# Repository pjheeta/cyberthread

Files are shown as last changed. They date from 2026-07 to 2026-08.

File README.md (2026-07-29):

# cyberthread

**WiFi-controlled fibre-optic hair for Burning Man.** Eight side-glow fibres woven
into braided hair, each lit by its own addressable LED. The electronics live in a
small box on the chest; only passive glowing fibre goes in the hair. Colour, patterns,
and a mic-reactive "glitch" mode are driven from an ESP32 and controlled from a phone.

The name is the concept: the *thread* is both the fibre woven through the hair and the
data thread driving it.

> **Status: pre-build / design complete.** The hard part (the fibre-to-LED coupler) is
> solved and printable. Remaining work is gated on one set of physical measurements
> taken with the strip in hand — see [Open items](#open-items).

---

## How it works

```
  phone ──WiFi──▶ ESP32 ──DAT/CLK──▶ SK9822 pixels ──▶ COUPLER ──▶ fibre ──▶ hair
                    ▲                 (8, in the box)   (the      (side-    (8 passive
                 I2S mic                                 custom     glow)     strands)
               (glitch mode)                             part)
```

A fibre makes no light of its own — it's a light pipe. Shine an LED into one end and
the whole strand glows that colour. So the design keeps every electronic part in a box
and sends only light up into the hair:

1. **ESP32-WROOM-32** runs the show — WiFi access point, phone web UI, render loop.
2. **8× SK9822 pixels** (APA102-family, clock + data) sit *in the box* as the light
   engine. One pixel per fibre = per-strand colour control.
3. The **coupler** presses each fibre end against its pixel. This is the only custom-
   fabricated part and the thing the whole build hinges on.
4. **Side-glow fibre** carries the light up and glows along its length.
5. An **INMP441 I²S mic** feeds amplitude to the ESP32 for the sound-reactive mode.

Firmware is either **WLED** (free, has an AudioReactive usermod that supports the
INMP441 natively — no code) or hand-rolled FastLED (SK9822 is already familiar from a
prior POV-wheel project).

### Why fibre and not LED strip in the hair

A strip *can* go in the hair and gives real per-pixel "rain" down each strand — but a
flat flex-PCB doesn't drape; it reads as hardware braided into hair. Fibre drapes like
hair and looks like the hair itself is glowing. The trade is that fibre has no spatial
resolution along its length (a single fibre is one colour end-to-end), so per-strand
addressability is the ceiling, not per-*pixel* rain down a strand. That trade was made
deliberately: the look won.

---

## The coupler

A small block with a **groove** on the underside and a **row of holes** through the top.

- The SK9822 strip drops into the groove. The groove is sized to the strip width so it
  can only sit one way — which **auto-aligns every LED under its hole.** No aligning by
  eye.
- Each hole holds one fibre pointed straight down at one LED. The fibre bottoms out
  **dry against the LED face** — nothing in the optical gap.
- A dab of glue on the fibre shaft *above* the block retains it. **Never glue in the
  hole or on the LED** — it fogs the light path and can't be undone.

It's parametric ([`hardware/coupler/cyberthread_coupler.scad`](hardware/coupler)): the
same file makes the block for any strip density by changing `pitch` and `strip_w`.

| Strip | Pitch (c-c) | Strip width | Block length | Print |
|---|---|---|---|---|
| 30 LED/m  | ~28–33 mm* | 10 mm | ~212 mm | full, or 2× halves |
| 100 LED/m | ~10 mm | 10 mm | ~78 mm | single piece |
| 144 LED/m | ~6.94 mm | 12 mm | ~65 mm | single piece |

\* *Pitch to be confirmed by measurement — see Open items. The LED itself is a fixed
5×5 mm (5050) package at every density; only spacing changes.*

**Print notes:** black **PETG** (not PLA — softens in a warm box; not CF — rough holes,
needs a hardened nozzle). Orient channel-opening **up** → holes print clean, no
supports, no bridging. FDM shrinks holes slightly, so **test-fit a fibre and tune
`hole_comp`** before printing the final part.

---

## Bill of materials

| Part | Spec | Notes |
|---|---|---|
| Controller | ESP32-WROOM-32 | owned |
| Light engine | 8× SK9822 pixels | cut from strip stock; owned |
| Fibre | 2 mm side-glow PMMA, ~10 m | **not** end-glow. Long-lead item — order first |
| Coupler | black PETG print | the one fabricated part; STLs in repo |
| Mic | INMP441 (I²S) | optional; enables glitch mode. 3.3 V, not 5 V |
| Box | plastic project box | **never metal** — kills the WiFi AP |
| Power | USB power bank | ~1 A draw → runs all night |
| Chain | 550 paracord + black heatshrink | paracord carries load; fibre carries none |
| Safety | magnetic breakaway | necklace in a crowd must pop apart when snagged |
| Coat | acrylic conformal coating | playa dust is alkaline/conductive |

Realistic out-of-pocket, owning the ESP32/SK9822/consumables: **~$50–75.**

---

## Repo layout

```
cyberthread/
├── README.md
├── hardware/
│   └── coupler/
│       ├── cyberthread_coupler.scad     ← parametric source (edit this)
│       ├── coupler_30ledm_FULL.stl
│       ├── coupler_30ledm_LEFT_half.stl
│       ├── coupler_30ledm_RIGHT_half.stl
│       ├── coupler_144ledm_FULL.stl
│       └── PRINT.md                      ← print + fit-test instructions
├── firmware/                             ← WLED config / FastLED sketch (TBD)
└── docs/
    └── build-guide.html                  ← illustrated build guide
```

---

## Build sequence

1. **Dark-room test first.** One pixel, one polished fibre, lights off. Confirms the
   whole idea reads before anything is fabricated.
2. Cut an 8-pixel SK9822 run; solder `5V/GND/DAT/CLK` to the **input** end (arrows point
   away from it). Avoid the 0.5 m factory solder-joints — pitch is irregular there.
3. Flash the ESP32 (WLED or FastLED); get pixels + phone control working on the bench.
4. Print the coupler; **test-fit a fibre**, tune `hole_comp`, reprint if needed.
5. Prep fibres (razor-cut, sand, flame-polish), seat dry, retain from behind, wrap the
   junction reflective.
6. Bench-test all 8 strands. Dull strand = re-seat that fibre. Then soak-test on
   battery for runtime + heat.
7. Chain: paracord core + heatshrink jacket + magnetic breakaway.
8. Braid in, dress-rehearse in the dark on battery before the playa.

---

## Open items

Everything below is gated on measuring the **actual strip** (blocked until home ~Aug 10):

- [ ] **Centre-to-centre pitch** — ruler on centre of LED #1, read centre of LED #11,
      ÷10. Ends the 28-vs-33 mm ambiguity for the 30/m strip.
- [ ] **Which density** is actually being used (30 / 100 / 144) → picks the block.
- [ ] **Fibre outer diameter** → sizes the holes (`fiber_d`, currently assumed 2 mm).
- [ ] Confirm side-glow fibre is **ordered / en route** (the long pole).
- [ ] Firmware decision: WLED vs. hand-rolled FastLED.

Once measured, regenerating the correct STL is a two-line edit to the `.scad`.

---

## Lessons / decisions log

- Fibre must be **side-glow**, not end-glow, or it only lights at the tip.
- Coupling is the whole game: a scissor-crushed or unpolished fibre end scatters light;
  an air gap or glued gap kills brightness. Razor-cut, sand, flame-polish, seat dry.
- **The LED is a constant 5050 (5×5 mm) at every density** — only pitch/width change,
  which is why one parametric file covers all strips.
- Nominal pitch (`1000 ÷ density`) is *not* reliable — factory spacing and 0.5 m splices
  drift it. Measure, don't assume; a per-hole error accumulates to a total miss by hole 8.
- Power bank on the belt beats a LiPo on the neck (heat/puncture); a night-only piece
  never bakes, so hot glue and simple sealing are fine.

---

*Personal build. Shared in case it's useful to anyone chasing the same look.*

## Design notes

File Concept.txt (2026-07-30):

Path A — WLED: you flash, you don't write. WLED is C++/Arduino firmware, so "no issues with Arduino" makes it fully available to you — but you barely touch code. You flash the binary, open its web UI, tell it "SK9822, 8 pixels, these pins," enable the AudioReactive usermod for your INMP441, and you're done. The entire architecture I walked through — two-core split, mode table, web layer, mic subsystem, NVS persistence — you inherit, pre-built and battle-tested. Your work becomes configuration, not programming.

how would I control it on the palya

Good — WLED it is, and "how do I control it on the playa" is exactly the right question to poke at, because the playa breaks the assumptions WLED's control model is normally built on. Let me walk through how control actually works, then the three things about the playa specifically that you have to design around.

How WLED control works, normally

WLED serves its own web interface. You connect a phone to it and control it from a browser or the WLED app — brightness, color, effect, speed, on/off, presets. There's no cloud, no account, nothing phones home. That "no internet needed" part is what makes it viable out there at all.

But there's a catch in the default setup: out of the box, WLED wants to join your home WiFi, and you control it as another device on that network. There is no home WiFi on the playa. So the default model doesn't apply, and this is the thing to get right before you go.

The mode that actually works out there: AP mode

WLED has a built-in access point — the ESP32 broadcasts its own WiFi network. Your phone connects directly to the wearable itself; no router, no infrastructure. This is the playa answer.

How it behaves: when WLED boots and can't find a known network (which is always, out there), it falls back to broadcasting an AP — typically named WLED-AP. You connect your phone to that network, and WLED's control page opens automatically (a captive portal, like a hotel WiFi splash). From there you have the full interface.

To make this reliable, before you leave you'd set WLED to AP mode always-on (not just as a fallback) in its WiFi settings, so it isn't wasting time scanning for home networks that aren't there. You give the AP a name and a password so it's yours and not open to every passerby.

So the on-playa flow is: wearable powers on → broadcasts its AP → you open your phone's WiFi, tap your network, the control page appears → change color/effect/brightness/mode. That's it. Works in the deep playa with zero infrastructure.

Now the three playa-specific problems, because the above is the easy version:

1. Your phone fights you over the "no internet" network. This is the one that'll actually bite you. When your phone connects to an AP with no internet — which WLED's AP is — modern phones detect "no internet here" and often auto-disconnect, or pop "this network has no internet, stay connected?" every time, or silently drop back to cellular. On the playa, where you'll connect and reconnect a lot, this is genuinely annoying. Mitigations: tell your phone to stay connected to this network / disable "auto-switch to mobile data" for it, and on Android turn off "switch to mobile network if no internet." Set this up and test it at home before you go, because fighting your phone's captive-portal logic at 2 a.m. in the dust is miserable.

2. RF soup. The playa is thousands of people, hotspots, LED-suit controllers, everyone's phone. 2.4 GHz gets crowded. AP mode helps because you're the only client on your own network, but connection can still be flaky in a dense crowd. Practical answer: you don't need a persistent connection. You connect, change the look, disconnect. WLED keeps running the selected mode with no phone attached. So treat control as "occasional adjustment," not "live tether."

3. You often can't reach your phone, or don't want to. Half the time you're dancing, riding, hands full, phone buried. So lean on WLED features that mean you don't need the phone most of the night:

Presets + playlists. Save your favorite looks as presets, then build a playlist that auto-cycles through them on a timer. Set it once; it runs all night untouched. This is the big one for a wearable — you may barely touch the phone after setup.
Macros / on-boot preset. WLED can boot straight into a chosen preset, so it comes up right every time you swap the battery.
The mic mode is autonomous. AudioReactive glitch mode needs no phone at all — it just reacts to the music around you. Set it and forget it.
The honest recommendation for playa control: set up AP mode always-on, build 3–5 presets (your purple, your glitch, a slow breathing fade, etc.) and a playlist that cycles them, and set a boot preset. Then the phone becomes optional — you pull it out only when you want to deliberately override the look, connect, tap, disconnect. That's far more robust than expecting a live connection to hold in that environment.

One thing worth knowing exists, though I'd not rely on it: WLED supports physical controls too — a button on a GPIO can cycle presets or toggle power. For a wearable where the phone is a hassle to reach, a single concealed button at your chest box that advances through your presets is a really nice touch. No phone at all: press to change look. If you want that, it's one more GPIO and a config line, and it might be the most playa-appropriate control of all — because it works with dusty hands, no screen, no reconnecting.

Want me to lay out the specific WLED settings to configure before you leave — the AP setup, the preset/playlist structure, the boot preset, and optionally that hardware button — as a pre-departure checklist you can run through at home while you still have a calm network to test on?

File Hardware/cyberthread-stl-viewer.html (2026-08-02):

CYBERTHREAD·STL viewerPRO

Open STL Wireframe Grid Bounds Spin Light Reset view

### Model

file—

triangles—

size X—

size Y—

size Z—

longest—

drag orbit scroll zoom

right-drag / shift-drag pan

## Drop an STL file here

Or click Open STL. Handles both ASCII and binary STL, including the 80-byte-header binaries that trip up naive parsers. Units are read as millimetres.

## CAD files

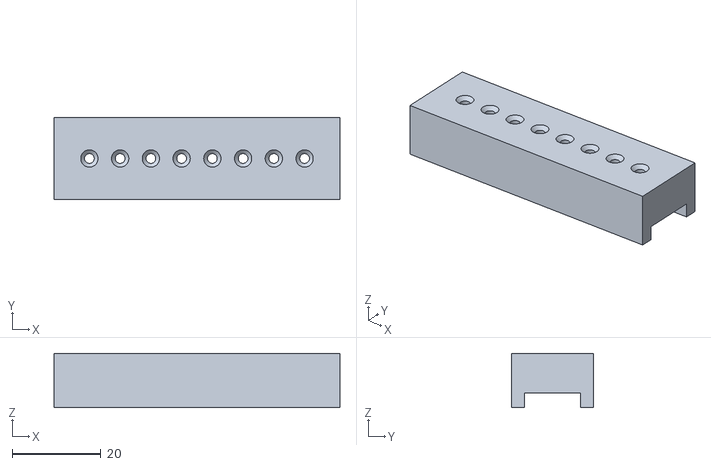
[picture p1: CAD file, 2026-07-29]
Hardware/coupler_144ledm_FULL.stl
64.6 x 18.6 x 12.3

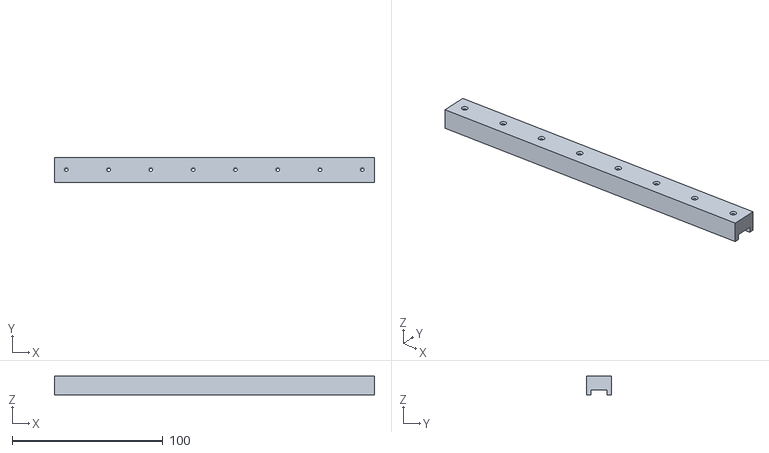
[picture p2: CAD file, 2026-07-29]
Hardware/coupler_30ledm_FULL.stl
212.0 x 16.6 x 12.3

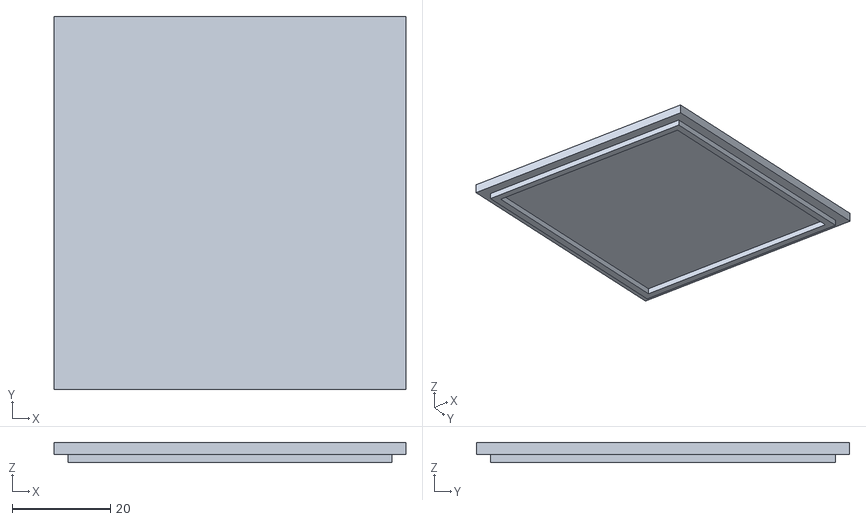
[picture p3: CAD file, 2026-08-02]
Hardware/enclosure_144_LID.stl
71.6 x 75.9 x 4.10

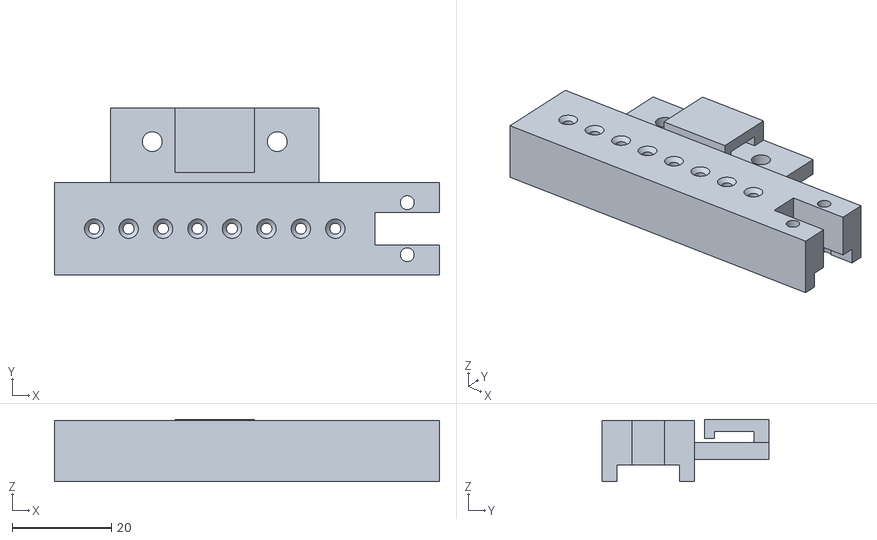
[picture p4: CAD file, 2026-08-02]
Hardware/coupler_144_NECKMOUNT.stl
77.6 x 33.6 x 12.5

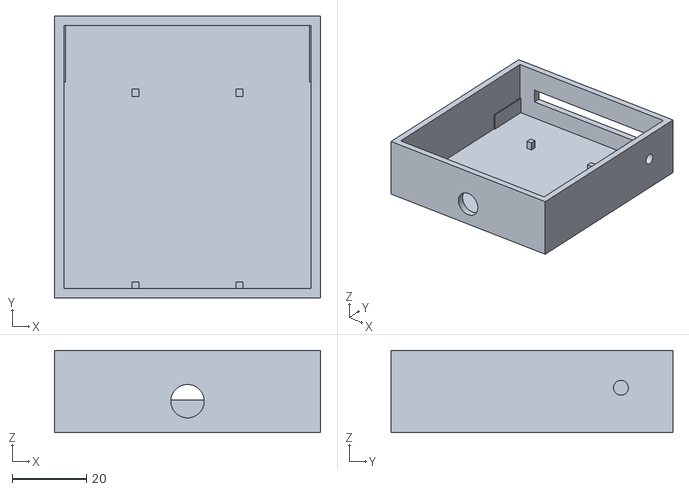
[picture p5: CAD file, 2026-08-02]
Hardware/enclosure_144_TRAY.stl
71.6 x 75.9 x 22.2

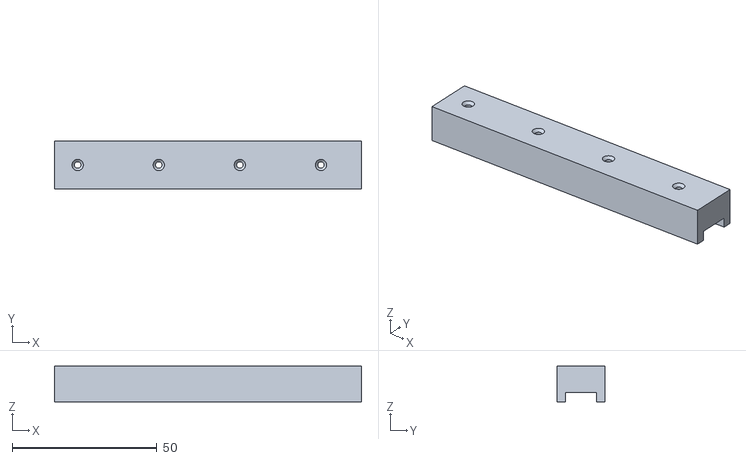
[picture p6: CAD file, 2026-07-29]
Hardware/coupler_30ledm_LEFT_half.stl
106.0 x 16.6 x 12.3

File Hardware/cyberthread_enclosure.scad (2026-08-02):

// ============================================================
//  CYBERTHREAD — printed enclosure (v0, parametric)
//  The coupler drops in at the TOP; fibres exit the top wall
//  and run up to the hair. The ESP32 sits in the body. USB
//  power enters the bottom (battery lives on your belt).
//  Prints as a tray (open top) + a friction-fit lid.
// ============================================================

/* ---- coupler outer size (match your coupler .scad output) ---- */
cpl_l = 65;     // length / hole-row.  144/m = 65,  30/m = 212
cpl_w = 18.6;   // width.              144/m = 18.6, 30/m = 16.6
cpl_h = 12.3;   // height

/* ---- ESP32 board bay   ### CONFIRM your board's real size ### ---- */
esp_l = 52;     // board length (38-pin devkit ~ 52; 30-pin ~ 48)
esp_w = 28;     // board width  (~ 25.4–28)
esp_h = 13;     // height incl. header pins

/* ---- build params ---- */
wall    = 2.5;
floor_t = 2.0;
clr     = 0.8;   // clearance around parts
gap     = 5;     // gap between coupler and ESP bay
usb_d   = 9;     // USB cable pass-through (fits a grommet)
mic_d   = 4;     // mic port
lip     = 1.6;   // lid lip depth
lip_clr = 0.35;  // lid fit clearance
$fn = 48;

/* ---- derived ---- */
in_x  = max(cpl_l, esp_w) + 2*clr;
in_y  = cpl_h + gap + esp_l + 2*clr;
in_z  = max(cpl_w, esp_h) + 2*clr;
out_x = in_x + 2*wall;
out_y = in_y + 2*wall;
tray_h = floor_t + in_z;

// key interior anchors
cpl_y0 = wall + in_y - cpl_h;      // coupler pushed against +Y wall
cpl_x0 = wall + (in_x-cpl_l)/2;
slot_z = floor_t + cpl_w/2;        // fibre row height
esp_y0 = wall + clr;               // ESP at the bottom (low Y)
esp_x0 = wall + (in_x-esp_w)/2;

module tray() {
  difference() {
    cube([out_x, out_y, tray_h]);                 // shell
    translate([wall, wall, floor_t])
      cube([in_x, in_y, in_z + 2]);               // hollow, open top

    // fibre exit slot in +Y wall, aligned to the hole row
    slot_len = cpl_l - 12;
    translate([out_x/2 - slot_len/2, out_y - wall - 0.6, slot_z - 2.5])
      cube([slot_len, wall + 1.2, 5]);

    // USB power entry, -Y wall, at ESP height
    translate([out_x/2, -0.6, floor_t + esp_h/2])
      rotate([-90,0,0]) cylinder(d=usb_d, h=wall+1.2);

    // mic port, +X side wall, up near the coupler end
    translate([out_x-wall-0.6, out_y - 14, floor_t + in_z/2])
      rotate([0,90,0]) cylinder(d=mic_d, h=wall+1.2);
  }

  // coupler locating ribs (stop it sliding in X, hold against +Y wall)
  for (x=[cpl_x0-2.4, cpl_x0+cpl_l+0.4])
    translate([x, cpl_y0-3, floor_t]) cube([2, cpl_h+3, min(cpl_w,6)]);

  // ESP corner nubs (board drops between them; tape/glue to secure)
  for (dx=[0, esp_w], dy=[0, esp_l])
    translate([esp_x0+dx-1, esp_y0+dy-1, floor_t]) cube([2,2,3]);
}

module lid() {
  translate([0, out_y + 8, 0]) {
    cube([out_x, out_y, wall]);                    // plate
    // lip that drops into the interior
    translate([wall+lip_clr, wall+lip_clr, -lip])
      difference(){
        cube([in_x-2*lip_clr, in_y-2*lip_clr, lip]);
        translate([2,2,-1]) cube([in_x-2*lip_clr-4, in_y-2*lip_clr-4, lip+2]);
      }
  }
}

tray();
lid();

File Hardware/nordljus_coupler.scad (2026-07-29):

// ============================================================
//  NORDLJUS — SK9822 -> fibre coupler block   (parametric)
//  Holds 8 fibres, one over each LED. The strip drops into a
//  channel on the underside so the holes self-align to the LEDs.
//
//  MEASURED VALUES (from BTF spec sheet):
//    30 LED/m  : pitch 28.0 mm, strip width 10 mm
//    144 LED/m : pitch 6.94 mm, strip width 12 mm
// ============================================================

pitch      = 28.0;      // 30/m = 28.0  |  144/m = 6.944   ### confirm ###
strip_w    = 10.0;      // 30/m = 10    |  144/m = 12
fiber_d    = 2.0;       // fibre OUTER diameter (mm)        ### measure ###
num_holes  = 8;

hole_comp  = 0.20;      // FDM hole-shrink compensation (tune on a test print)
strip_clr  = 0.6;
pcb_t      = 1.0;
led_h      = 1.8;
roof       = 9.0;
wall       = 3.0;
end_margin = 8.0;
chamfer    = 0.9;

segment    = 0;         // 0 full | 1 LEFT half | 2 RIGHT half

$fn = 64;

hole_d    = fiber_d + hole_comp;
channel_w = strip_w + strip_clr;
channel_d = pcb_t + led_h + 0.5;
height    = channel_d + roof;
width     = channel_w + 2*wall;
length    = 2*end_margin + (num_holes-1)*pitch;
x_split   = end_margin + (num_holes/2 - 0.5)*pitch;
function hx(i) = end_margin + i*pitch;

module block_full() {
  difference() {
    cube([length, width, height]);
    translate([-1, (width-channel_w)/2, -0.1])
      cube([length+2, channel_w, channel_d+0.1]);
    for (i=[0:num_holes-1])
      translate([hx(i), width/2, channel_d-0.1])
        cylinder(d=hole_d, h=height-channel_d+0.2);
    for (i=[0:num_holes-1])
      translate([hx(i), width/2, height-chamfer])
        cylinder(d1=hole_d, d2=hole_d+2*chamfer, h=chamfer+0.05);
  }
}

if (segment==0) block_full();
else if (segment==1)
  intersection(){ block_full(); translate([-1,-1,-1]) cube([x_split+1, width+2, height+2]); }
else
  intersection(){ block_full(); translate([x_split,-1,-1]) cube([length-x_split+1, width+2, height+2]); }

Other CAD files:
Hardware/coupler_30ledm_RIGHT_half.stl

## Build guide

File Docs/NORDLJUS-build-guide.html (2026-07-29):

# Nordljus

Fibre-optic hair system · WiFi · 8 strand

Assembly Instructions ESP32-WROOM-32 · APA102 Design no. BRC-26

All electronics stay in the box. Only passive fibre goes in your hair. Read every panel before you cut anything — steps 1 and 2 decide how bright this ends up, and they are the two you cannot redo without starting over.

## Parts

ESP32-WROOM-32

×1

you own this

74AHCT125

×1

level shifter, DIP

APA102 pixels

×8

cut from bike-wheel stock

Side-glow fibre

10 m

3 mm PMMA · not end-glow

INMP441 mic

×1

I²S digital

Capacitors

3+

1000 µF · 470 µF · 0.1 µF

USB power bank

×2

10 000 mAh · on your belt

Project box

×1

plastic only — never metal

Magnetic breakaway

×1

safety disconnect

Coupling block

×1

8 holes · you make this

550 paracord

1 m

carries all the weight

Heatshrink

1 kit

black · 3:1 adhesive-lined

Conformal coat

×1

dust is corrosive

Grommets + fuse

1 kit

seal every box exit

Grey = already in your parts drawer

## Assembly

1

Do not rush this

Cut 8 fibres, each about 70 cm (box → top of head → down the braid, plus slack). Cut with a fresh razor blade against a hard surface — never scissors. Scissors crush the core and the end scatters light instead of accepting it. Then sand the LED end flat on fine paper and flame-polish it briefly until it goes glassy. This single surface is the biggest brightness lever in the whole build.

2

Make the one hard part once

Drill 8 holes in one block — Delrin, aluminium, or a print — at exactly your strip's pixel pitch (144/m ≈ 6.9 mm; measure yours). Size them so fibre press-fits snugly. The fibre end must physically touch the pixel's face: an air gap throws light away. Wrap the whole junction in reflective tape or white heatshrink to bounce stray photons back into the fibre. Doing all eight couplings as one part is the entire reason this build is tractable.

3

Cut an 8-pixel run from your APA102 strip and solder four wires to its input end: 5V, GND, DI, CI. The strip has arrows printed on it — data flows one way only. Solder to the end the arrows point away from, or nothing lights and you will blame the code.

4

The hour-eating mistake lives here

Power the shifter at 5V (single-supply — that's how it reads 3.3 V as HIGH and puts out clean 5 V). Add a 0.1 µF across its Vcc/GND. Tie pins 1 and 4 (/OE) to GND. They are active-low; leave them floating and the outputs stay dark while every wire looks perfect. This is the single most common way to lose an evening on this build.

5

Wire the mic for glitch mode. L/R to GND puts it on the left channel — your I²S read expects that. Mount it so the little port hole faces out of the box toward the music, not into a wiring bundle.

6

Brownout insurance

Feed pixel 5 V from the rail directly — never through the ESP32's regulator. Star all grounds to one point. Then the caps: 1000 µF across the rail near the pixels, 470 µF across the ESP32's 3V3/GND. That second one is not optional — ESP32 WiFi transmit spikes hard, and without it you get Brownout detector was triggered resets mid-show, on playa, in the dark.

7

Before glue. Before coat. Before anything.

Flash it, join the AP from your phone, cycle every mode, and check that all eight strands light and match. A dull strand means a bad coupling — pull that fibre, re-polish, re-seat. Do this while everything is still open and reversible. Every mistake in this build is cheap right now and expensive in four steps' time.

8

Brush conformal coat over the board and solder joints — mask the mic port, the connectors, and the pixel faces. Drop silica gel in the box. Grommet and hot-glue every cable exit. Playa dust is alkaline and mildly conductive; uncoated joints start failing around day four.

9

Cord takes the load. Fibre takes none.

Bundle the paracord and all 8 fibres, then sleeve the lot in black heatshrink — that's your chain. The paracord is anchored at both ends and carries every gram; the fibre floats loose inside carrying nothing. If the fibre ever takes the box's weight, it will creep, whiten, and dim over a week of movement. Add strain relief where the chain enters the box and where it meets the braid — both flex points.

10

Fit the magnetic breakaway in the chain between box and head. Braid the 8 fibres into tight tracks against the scalp so the surrounding hair conceals them and only the glow shows. The breakaway is a genuine safety part — anything worn around the neck in a crowd of bikes and hugs must come apart when it snags, not pull your head with it.

## Do not

A metal enclosureFaraday cage. Your AP dies inside it and you will debug firmware for a night. Plastic only, and keep the antenna end clear.

A LiPo pouch on your neckCrush, puncture, dust-short — and a cell that vents does it against your throat. Power bank on the belt, always.

Scissors on fibreA crushed end scatters light back out instead of accepting it. Razor, sand, flame-polish. Every time.

Floating /OE pinsPins 1 and 4 to GND. Otherwise: perfect wiring, correct code, zero light, four lost hours.

Fibre bearing the box's weightAnchor the paracord at both ends. Loaded fibre creeps and dims over a week of movement.

Sealing before you bench-testStep 7 exists so that a bad coupling costs you a minute, not a rebuild. Nothing gets glued until all eight strands light.

## Cost

Item | New | Yours
ESP32-WROOM-32in your drawer | $7 | $0
APA102 pixels8 cut from bike-wheel stock | $18 | $0
Capacitors, silicone wire, heatshrink, paracordexisting kits | $40 | $0
Side-glow fibre, 10 m3 mm PMMA — buy long, you'll ruin ends learning to polish | $20 | $20
USB power banks ×2the single biggest line; swap-and-solar for the week | $45 | $45
Conformal coatingnon-negotiable for dust | $14 | $14
Magnetic breakaway + magnetic USB-Csafety, twice | $22 | $22
Project box (plastic) | $10 | $10
INMP441 micships as a 3–5 pack | $8 | $8
74AHCT125 level shifter | $5 | $5
Coupling block stockDelrin offcut, or free if you print it | $8 | $8
Grommets, PTC fuse, silica | $18 | $18
Spare ESP32buy it. one brownout-bricked board on playa ends the project | $7 | $7
Total | $222 | $157

If a strand goes dark, it is the coupling — not the code. Pull the fibre, re-polish the end, re-seat it against the pixel. It is the coupling roughly every time.

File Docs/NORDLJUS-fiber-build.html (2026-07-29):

# Nordljus

Fibre-optic hair system · SK9822 light engine

Build & Coupler GuideESP32 · SK9822 · 8 fibreDesign no. BRC-26 · rev C

Eight LEDs live in a box on your chest. Eight fibres carry their light up into your braids. Nothing electronic goes in your hair — only glowing plastic. The whole build is parts you already own, plus fibre. The one thing you fabricate, and the one thing that decides whether this looks brilliant or dim, is the coupler — so this guide is built around it.

What changed from the strip idea: the SK9822 strip is no longer worn in your hair — it goes in the box as the light source. Fibre replaces it in the hair because fibre drapes and a strip does not. Same part you know from the bike wheel; new job.

## Parts

ESP32-WROOM-32

×1

you own this

SK9822 strip

8 px

from bike-wheel stock

Side-glow fibre

10 m

2 mm PMMA · not end-glow

INMP441 mic

×1

glitch mode · optional

Coupling block

×1

you make this

Project box

×1

plastic — never metal

Power bank

×1

~1A draw · runs all night

Mag breakaway

×1

safety disconnect

Paracord + heatshrink

kit

chain core & jacket

Reflective tape

scrap

wraps the coupler

Grey = already in your drawer

## How it fits together

## The coupler — in detail

A fibre makes no light of its own. It is a pipe: light shone into its end travels the length and (side-glow fibre) leaks out along the way, so the strand glows. The coupler is the junction where an SK9822 pixel's face meets a fibre's end. Get this right and the piece is bright and controllable. Get it wrong and no amount of good code or good fibre recovers it. Everything below is that junction, magnified.

One coupler, in cross-section — repeated eight times across the block

### The insight that makes it buildable: the block pitch is the strip pitch

You are not aligning eight fibres to eight LEDs by eye. The SK9822 strip already spaces its pixels at a fixed, repeating distance — its pixel pitch. Drill your block's holes at that exact spacing and every bore lands over a pixel automatically. Measure yours center-to-center: a 30 LED/m strip is about 33 mm pitch, so eight pixels span roughly 233 mm. That makes the block a long, slim bar — design the enclosure around a bar, not a cube. (If you want a compact block instead, cut the strip into single pixels and rejoin them with short DAT/CLK/5V/GND jumpers at a tighter pitch — more soldering, smaller part. Keeping the strip intact is the low-effort path.)

### The four things that must be true at every bore

Do this

Polished flat end, bottomed out, touching the lens, dry.

Not this

Air gap. Light spreads and misses the core — dim strand.

Not this

Crushed/scissor-cut end. Scatters light back out.

Not this

Glue in the gap. Fogs the lens, permanently dims it.

### Coupler assembly, bore by bore

1 · Prep the fibre end. Cut each fibre with a fresh razor against a hard surface — never scissors, which crush the core. Sand the end flat on fine paper, then pass it briefly through a flame until it goes glassy. This polished face is the single biggest brightness lever in the build.

2 · Bottom it out, dry. Press the polished end into its bore until it stops on the shelf, resting against the pixel's emitting face. There must be nothing between fibre and lens — no glue, no air you can help. Plastic touching plastic.

3 · Retain from behind. Put a small bead of adhesive on the fibre shaft where it exits the back of the block, never at the tip. The block sets the aim and distance; the glue only stops the fibre backing out.

4 · Wrap the junction. Sleeve the whole block-to-strip zone in reflective tape or white heatshrink. Stray light that would escape sideways gets bounced back into the fibres — free brightness, and it stops light leaking between neighbouring channels and muddying your per-strand colour.

5 · Keep it re-seatable. During bench test you will find a dull strand. A dry friction-fit lets you pull that one fibre, re-polish, and re-seat in thirty seconds. A fibre glued to the lens cannot be fixed. This is why steps 2 and 3 keep the optical face dry.

## Full build sequence

1

Test the idea before you build it

Before any box or block: wire one SK9822 pixel to the ESP32, press one polished fibre against it in a dark room, and look. This is the fifteen-minute test that tells you whether glowing fibre reads the way you're picturing. Fibre always looks dim in daylight and great in the dark — judge it where you'll wear it. If it's too dim even in the dark, fix the polish or the contact now, not after you've built eight of them.

2

Cut an 8-pixel run from the SK9822 strip. Solder four wires to its input end — 5V, GND, DAT, CLK. SK9822 is directional: the strip has arrows, and data flows one way. Solder to the end the arrows point away from, or nothing lights.

3

Wire the strip to the ESP32 over hardware SPI — the same DotStar setup you used on the bike wheel. In FastLED: FastLED.addLeds<SK9822, DATA_PIN, CLOCK_PIN, BGR>(leds, 8);. Because SK9822 carries its own clock, it shrugs off the jostling a wearable takes — no timing glitches when you move.

4

The one part you fabricate

Drill the coupling block at your strip's pixel pitch, one bore per pixel, each sized for a snug fibre press-fit with a shelf at the bottom so the fibre bottoms out against the lens without crushing it. Black/opaque material — a 3D print, Delrin, or black acrylic. See The coupler above; this is the step that decides everything.

5

Couple all eight fibres — prep, bottom out dry, retain from behind, wrap. Cut fibres long and polish after seating so any insertion damage sands away. Mount the block over the strip so each bore sits centred on its pixel.

6

Optional — glitch mode

Add the INMP441 mic if you want sound reactivity: VDD→3V3 (not 5V), L/R→GND, and the I²S trio to free GPIOs. On WLED, the AudioReactive usermod drives it for you. Mount the port facing out of the box toward the music.

7

Before you close anything

Power it on the bench, run every mode, and confirm all eight strands light and match. A dull one is a coupling — pull, re-polish, re-seat. Do this while everything is open and a fix costs a minute. Then run it on battery at full brightness for an hour and watch for heat and for how long the power bank actually lasts.

8

Build the chain: bundle the eight fibres with a 550 paracord core and sleeve the lot in black heatshrink. The paracord is anchored at both ends and carries all the weight; the fibres float loose inside carrying none — loaded fibre creeps and dims over a week. Fit the magnetic breakaway so a snag pops apart instead of pulling your head.

9

Braid the eight fibres into tight tracks against the scalp so surrounding hair hides the strands and only the glow shows. Strain-relieve where the chain enters the box and where it meets the braid — both are flex points that fatigue over the week.

## Cost

ESP32-WROOM-32in your drawer | $7 | $0
SK9822 pixels8 cut from bike-wheel stock | $0 | $0
Paracord, heatshrink, wire, power bank, reflective tapeexisting kits | $40 | $0
Side-glow fibre, 10 mbuy long — you'll ruin ends learning to polish | $18 | $18
Project box (plastic, bar-shaped) | $9 | $9
Magnetic breakaway | $9 | $9
Coupling block stockfree if you print it | $8 | $0–8
INMP441 micoptional — enables glitch mode | $6 | $6
Conformal coatrecommended — dust kills uncoated joints by mid-week | $14 | $14
Realistic out-of-pocket | $56 | ≈ $47

If a strand goes dark, it is the coupler — not the code. Pull that fibre, re-polish the end, re-seat it dry against the pixel. It is the coupler roughly every time. Everything electronic you already own or already understand; the craft in this build lives entirely at that junction.

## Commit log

2026-07-28 Add files via upload
    Added a STL viewer browser app
2026-08-02 added more 3D printable files for the cyberthread
    [coupler_144_NECKMOUNT.stl, cyberthread_enclosure.scad, enclosure_144_LID.stl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]
